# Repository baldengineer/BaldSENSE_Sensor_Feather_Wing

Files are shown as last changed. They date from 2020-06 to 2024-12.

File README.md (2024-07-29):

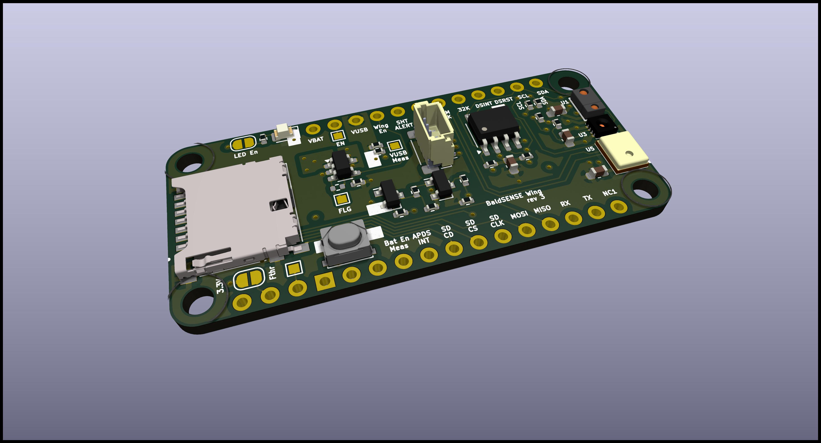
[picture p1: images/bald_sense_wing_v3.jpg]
render of BaldSENSE Sensor Feather Wing


## BaldSense Sensor Feather Wing
Project to fit a temperature, humidity, light, and sound sensor to an Adafruit Feather wing form factor.

Minimal environmental sensor board for characterizing a specific location. 

## Sensors Included:
- **Temp / Humidity**: 
    - SHT30-DIS-B2.5KS
- **Light**: 
    - APDS9960
- **Sound (Mic)**: 
    - MP34DT01TR-M
- **Real-Time Clock (RTC)**: 
    - DS3231S

## Status: Work In Progress
Originally created as a livestream project. Being updated for a long-term IoT project. 

V3 board fixes many issues with v1 and v2. Testing is underway with a [FeatherS3 board](https://unexpectedmaker.com/shop.html#!/FeatherS3/p/577111310/category=0) provided by [Unexpected Maker](https://unexpectedmaker.com). 

So far, each sensor is working as expected.

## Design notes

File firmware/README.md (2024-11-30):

Only [feathers3-cp](feathers3-cp/) is up-to-date.

It is basic logging code written in CircuitPython that works on a FeatherS3.

The `32u4` and `m0` code targeted rev2.

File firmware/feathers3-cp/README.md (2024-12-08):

# FeatherS3 Circuit Python

This code uses all of the intended BaldSENSE functions.

Couple of notes:
- Developed with a [FeatherS3](https://unexpectedmaker.com/shop.html#!/FeatherS3/p/577111310/category=0)
- Based on CircuitPython 9.x. 
- Publishes data to [Adafruit IO](https://io.adafruit.com)
    - It uses more feeds than the free version allows

## settings.toml.example
Remove the `.example` and place in the root directory of the `CIRCUITPY` mass storage device. 

### Required Settings:
- `WIFI_SSID` and `WIFI_PASSWORD` (your access point)
- `AIO_USERNAME` and `AIO_KEY` (Adafruit IO credentials)

### Optional, but recommended:
These settings have default values but you should set them.
- `BALDSENSE_ID` -> a unique identifier (defaults to `UNKNOWN`)
- `SLEEP_SECONDS` -> how long MCU goes to sleep between sampling (defaults to `600`)
- `WDT_SECONDS` -> watchdog timeout (defaults to `60`)
- `VUSB_THRESHOLD` -> voltage divider steps to detect when connected to power (defaults to `10000`)
- `UPDATE_TIME` -> force NTP update when connected to power. "No" or commented out skips this update.

### Not used (yet):
- `RUN_MODE` eventually to change behavior during devel or deploy
- `TIMEZONE` for setting timezone. current NTP method uses geo_ip
- `MQTT_BROKER` will use again in future to allow private broker

## Required Libraries
These are the required libraries. Dependencies are shown. The libraries listed with `.mpy` are single files and the others are directories in the [Adafruit CircuitPython (Library) Bundle](https://github.com/adafruit/Adafruit_CircuitPython_Bundle/releases). This code needs the `9.x` bundle.

### Sensors:
- adafruit_apds9960
- adafruit_ds3231.mpy
    - adafruit_register
- adafruit_sht31d.mpy

### AIO / MQTT:
- adafruit_io
- adafruit_minimqtt
    - adafruit_ticks.mpy
- adafruit_requests.mpy
    - adafruit_connection_manager

## mqtt_logger.py
Simple script to log MQTT messages to a file. Works well on Linux. 

## generate_time_string.py
Simple script to create a string with the system's current time to update the RTC. Copy/paste the string and press enter (line return). (You may need to re-enable the `while True` loop to get the timing right.)

Alternatively, when connected to USB, the code will check a NTP server.

## Sponsor
The PCB, components, and assembly for rev 3 have been provided by [MacroFab](https://macrofab.com).

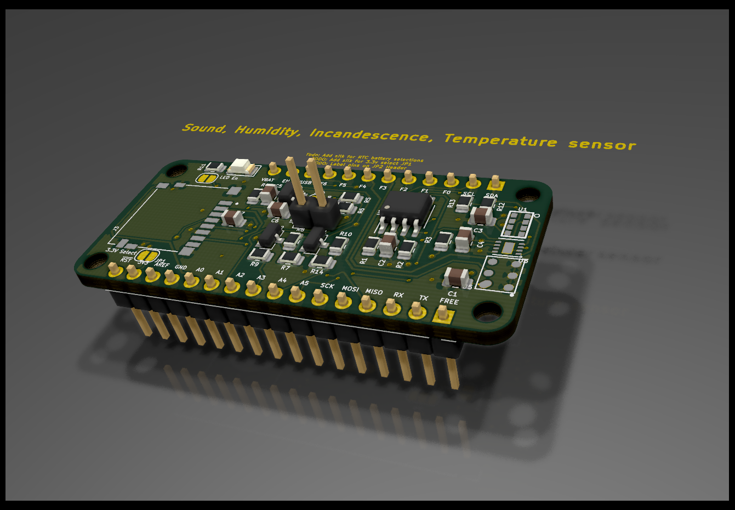
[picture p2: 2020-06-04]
images/Bald Sense Wing v1-second pass layout-ray.png

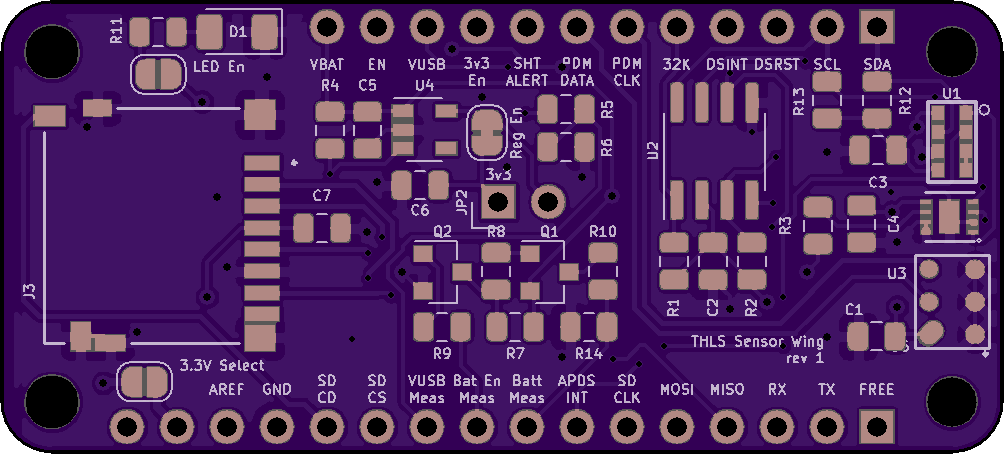
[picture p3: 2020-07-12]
images/pcb_render_oshpark_v1.png

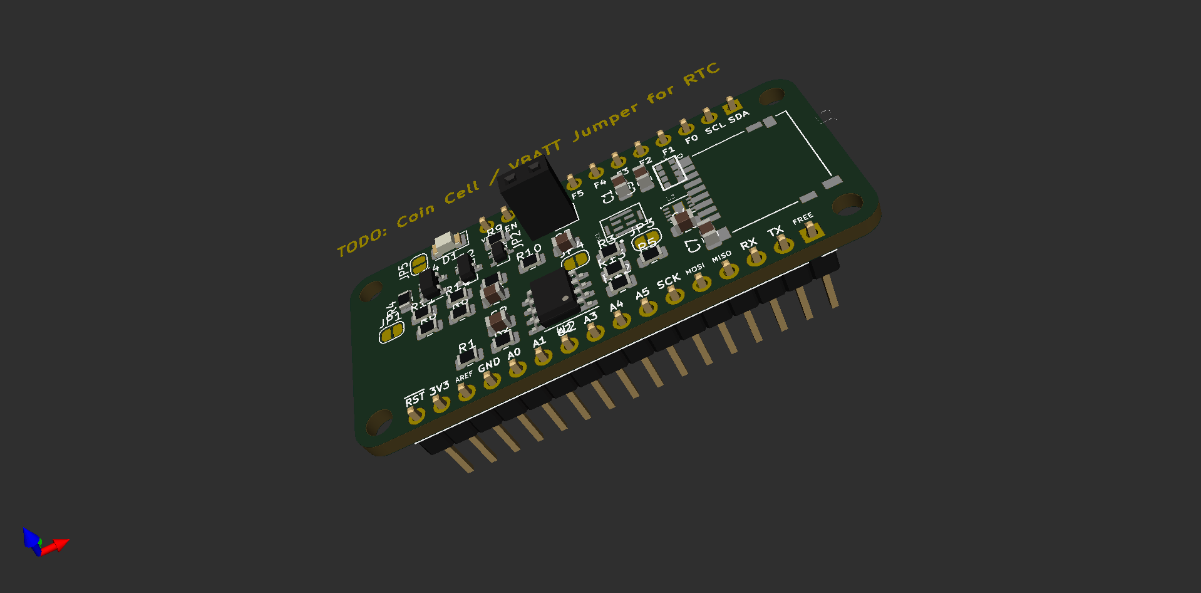
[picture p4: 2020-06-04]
images/Bald Sense Wing v1-first pass layout-flat.png

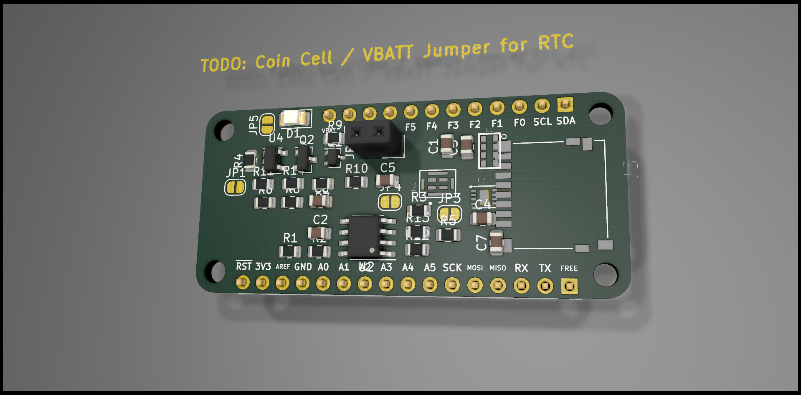
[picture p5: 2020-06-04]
images/Bald Sense Wing v1-first pass layout-ray.png

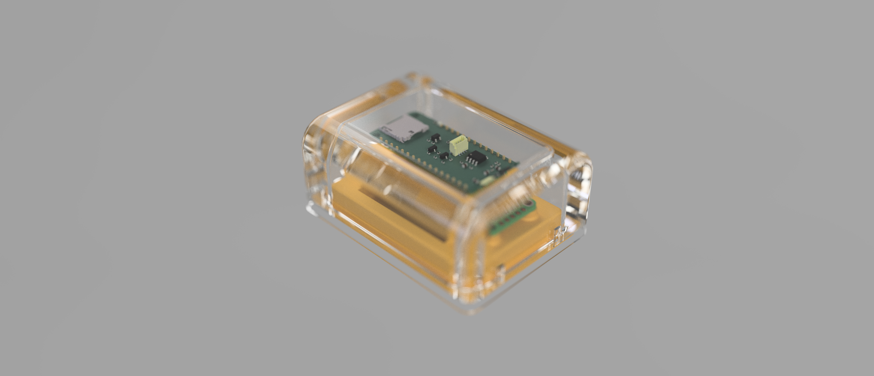
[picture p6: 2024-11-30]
enclosure/cover v7-polycarb with dof.png

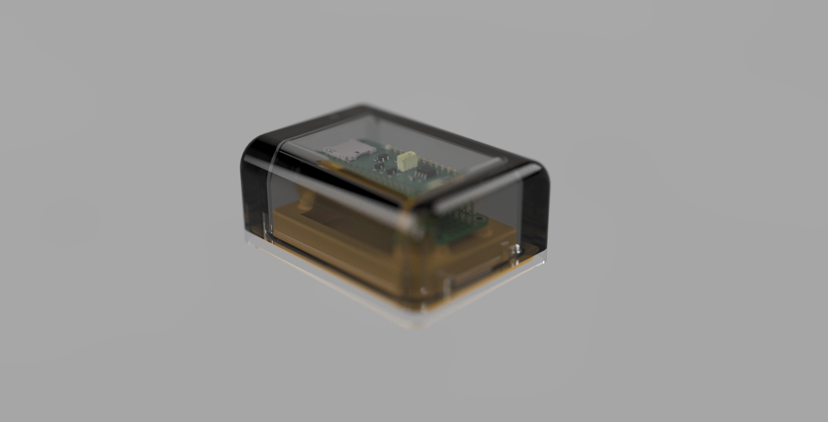
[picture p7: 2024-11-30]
enclosure/cover v7.png

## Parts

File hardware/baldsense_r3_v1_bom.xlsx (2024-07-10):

Designator | Value | Footprint | Populate | MPN | Manufacturer | MPN | Manufacturer
BT1 | 10mm | MPD_BK-870 | 0
C1 | 1uF | C_0603_1608Metric | 1 | LMK107B7105KAHT | Taiyo Yuden | MF-CAP-0805-1uF | MacroFab
C2 | 1uF | C_0603_1608Metric | 1 | LMK107B7105KAHT | Taiyo Yuden | MF-CAP-0805-1uF | MacroFab
C3 | 1uF | C_0603_1608Metric | 1 | LMK107B7105KAHT | Taiyo Yuden | MF-CAP-0805-1uF | MacroFab
C4 | 1uF | C_0603_1608Metric | 1 | LMK107B7105KAHT | Taiyo Yuden | MF-CAP-0805-1uF | MacroFab
C7 | 1uF | C_0603_1608Metric | 0 | LMK107B7105KAHT | Taiyo Yuden | MF-CAP-0805-1uF | MacroFab
D1 | PWR_LED | LED_0805_2012Metric | 1 | MF-LED-0805-GREEN | MacroFab
J1 | feather long | PinHeader_1x16_P2.54mm_Vertical | 0
J2 | feather short | PinHeader_1x12_P2.54mm_Vertical | 0
J3 | 1140084168 | AMPHENOL_1140084168 | 1 | 1140084168 | Amphenol
J4 | STEMMA-QT | JST_SH_BM04B-SRSS-TB_1x04-1MP_P1.00mm_Vertical | 0
JP1 | 3.3V | SolderJumper-2_P1.3mm_Open_RoundedPad1.0x1.5mm | 0
JP2 | RTC Batt Select | SolderJumper-3_P1.3mm_Bridged12_RoundedPad1.0x1.5mm | 0
JP3 | SHT30-Alert | SolderJumper-2_P1.3mm_Open_RoundedPad1.0x1.5mm | 0
JP5 | LED En | SolderJumper-2_P1.3mm_Open_RoundedPad1.0x1.5mm | 0
JP6 | RTC Batt Select | SolderJumper-3_P1.3mm_Bridged12_RoundedPad1.0x1.5mm | 0
Q1 | Q_PNP_BEC | SOT-23 | 1 | MMBT3906LT3G | onsemi | MF-DSC-SOT233-MMBT3906 | MacroFab
Q2 | Q_NPN_BEC | SOT-23 | 1 | MMBT3904LT3G | onsemi | MF-DSC-SOT233-MMBT3904 | MacroFab
R1 | 10K | R_0402_1005Metric | 1 | MF-RES-0402-10K | MacroFab
R10 | 10K | R_0402_1005Metric | 1 | MF-RES-0402-10K | MacroFab
R11 | 1K | R_0402_1005Metric | 1 | MF-RES-0402-1K | MacroFab
R12 | 10K | R_0402_1005Metric | 1 | MF-RES-0402-10K | MacroFab
R13 | 10K | R_0402_1005Metric | 1 | MF-RES-0402-10K | MacroFab
R14 | 10K | R_0402_1005Metric | 1 | MF-RES-0402-10K | MacroFab
R15 | 10K | R_0402_1005Metric | 0 | MF-RES-0402-10K | MacroFab
R16 | 10K | R_0402_1005Metric | 1 | MF-RES-0402-10K | MacroFab
R2 | 10K | R_0402_1005Metric | 1 | MF-RES-0402-10K | MacroFab
R3 | 10K | R_0402_1005Metric | 1 | MF-RES-0402-10K | MacroFab
R4 | 10K | R_0402_1005Metric | 1 | MF-RES-0402-10K | MacroFab
R5 | 10K | R_0402_1005Metric | 1 | MF-RES-0402-10K | MacroFab
R6 | 10K | R_0402_1005Metric | 1 | MF-RES-0402-10K | MacroFab
R7 | 10K | R_0402_1005Metric | 1 | MF-RES-0402-10K | MacroFab
R8 | 1K | R_0402_1005Metric | 1 | MF-RES-0402-1K | MacroFab
R9 | 1K | R_0402_1005Metric | 1 | MF-RES-0402-1K | MacroFab
SW1 | PTS810 | SW_SPST_PTS810_with_3D | 1 | PTS810SJK250SMTRLFS | C&K Components
TP1 | Test Point | TestPoint_Pad_1.0x1.0mm | 0
TP2 | Test Point | TestPoint_Pad_1.0x1.0mm | 0
TP3 | Test Point | TestPoint_Pad_1.0x1.0mm | 0
TP4 | Test Point | TestPoint_Pad_1.0x1.0mm | 0
TP5 | Test Point | TestPoint_Pad_1.0x1.0mm | 0
TP6 | Test Point | TestPoint_Pad_1.0x1.0mm | 0
TP7 | FLG | TestPoint_Pad_1.0x1.0mm | 0
TP8 | Test Point | TestPoint_Pad_1.0x1.0mm | 0
U1 | APDS-9960 | APDS-9960 | 1 | APDS-9960 | Broadcom
U2 | DS3231MZ | SOIC-8_3.9x4.9mm_P1.27mm | 1 | DS3231MZ | Dallas Semiconductor | DS3231MZ+ | Analog Devices
U3 | SHT30-DIS | DFN250X250X100-9N | 1 | SHT30-DIS | Sensirion | SHT30-DIS-P2.5KS | Sensirion
U4 | AP2151AW-7 | SOT-23-5 | 1 | AP2151AW-7 | Diodes Inc.
U5 | CMM-4737DT-26186-TR | XDCR_CMM-4737DT-26186-TR | 1 | CMM-4737DT-26186-TR | CUI Devices

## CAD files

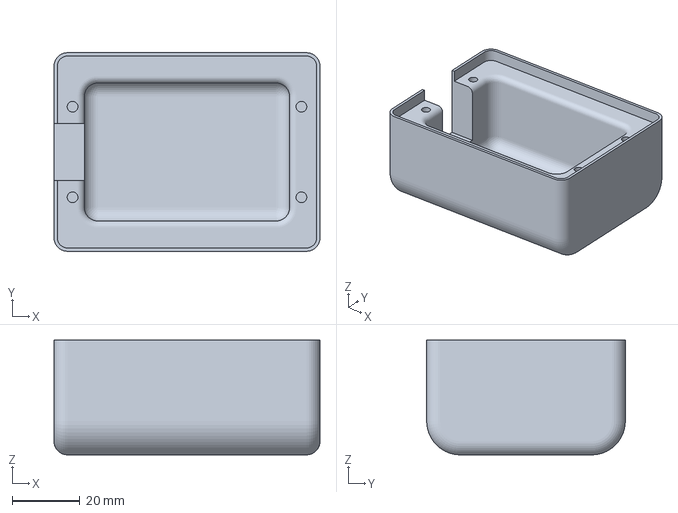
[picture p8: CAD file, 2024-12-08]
enclosure/Cover with USB Cutout.3mf
78.8 x 58.9 x 34.0 mm

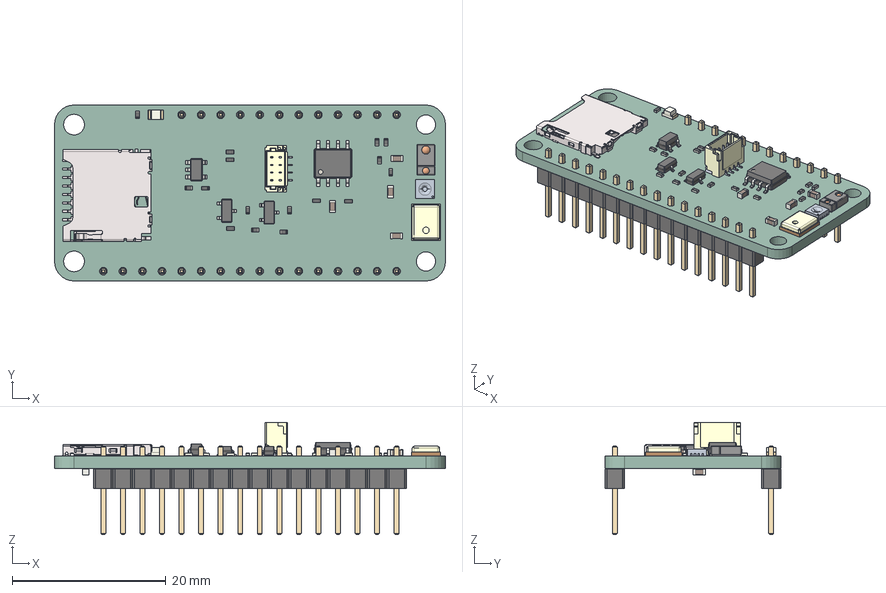
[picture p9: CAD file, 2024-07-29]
hardware/Bald Sense Wing v3.step
50.8 x 22.9 x 14.6 mm
C_0603_1608Metric x 5
LED_0805_2012Metric
R_0402_1005Metric x 16
ECA50C62-ABC2-4892-9E4C-4FA133A4C33F
SOIC_8_39x49mm_P127mm
CUI_DEVICES_CMM-4737DT-26186-TR
SOT_23 x 2
User Library-SHT3x
SOT_23_5
BM04B-SRSS-TBT(LF)(SN)
PinHeader_1x16_P254mm_Vertical
PinHeader_1x12_P254mm_Vertical
Bald Sense Wing v3_PCB

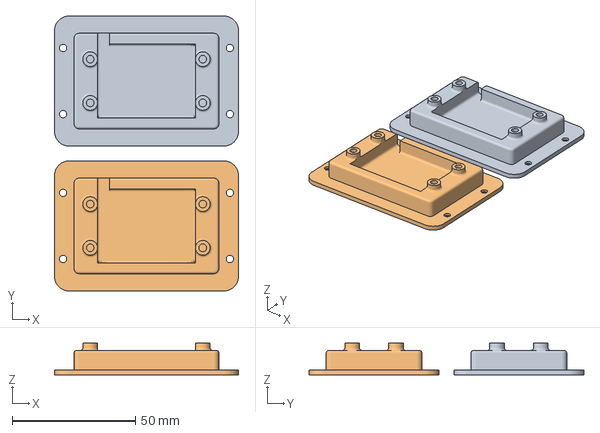
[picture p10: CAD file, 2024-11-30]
enclosure/Baseplate.3mf
74.8 x 111.7 x 13.0 mm
Baseplate.stl x 2

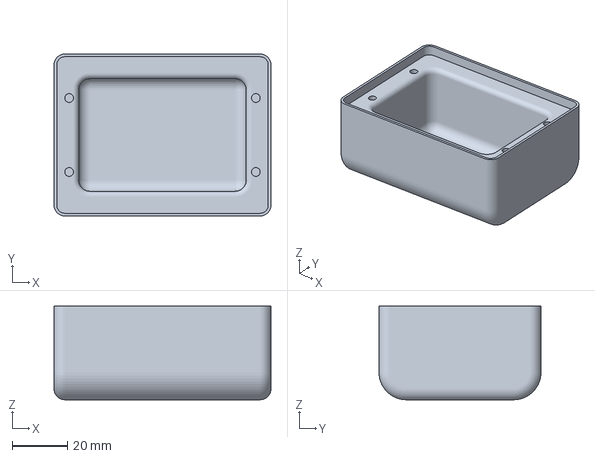
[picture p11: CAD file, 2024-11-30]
enclosure/Cover.3mf
78.8 x 58.9 x 34.0 mm

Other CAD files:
enclosure/Baseplate.stl
enclosure/Cover with USB Cutout.stl
enclosure/Cover.stl

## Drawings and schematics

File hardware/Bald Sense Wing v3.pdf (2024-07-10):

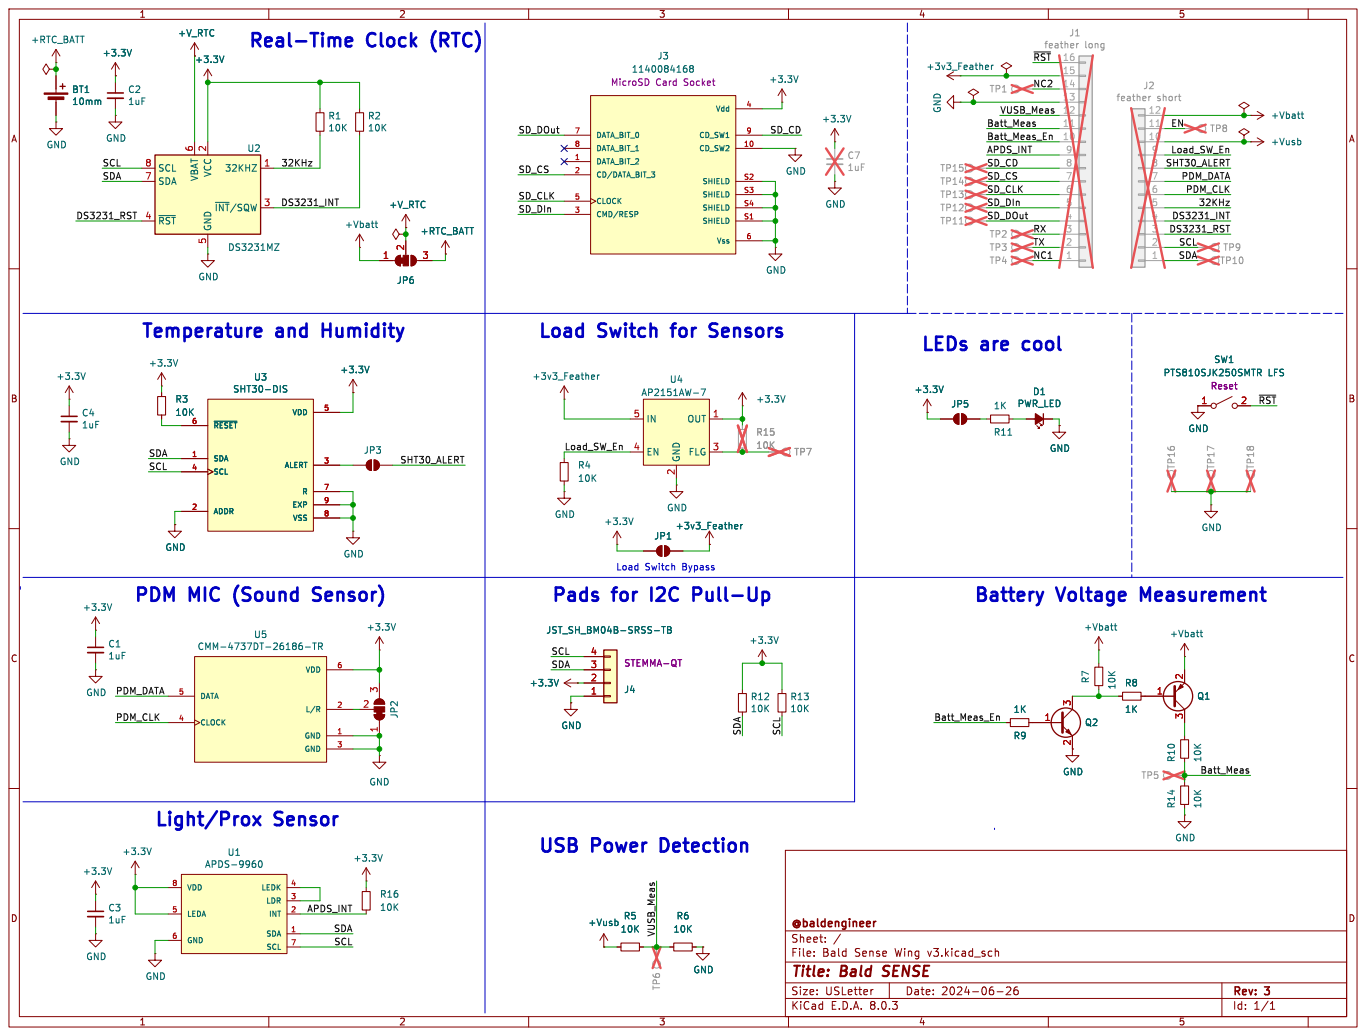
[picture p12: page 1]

6 SDA 7 SCL 8 U2 DS3231MZ GND GND GND

Load Switch for Sensors

Load Switch Bypass
Pads for I2C Pull-Up

Id: 1/1 Title: Bald SENSE

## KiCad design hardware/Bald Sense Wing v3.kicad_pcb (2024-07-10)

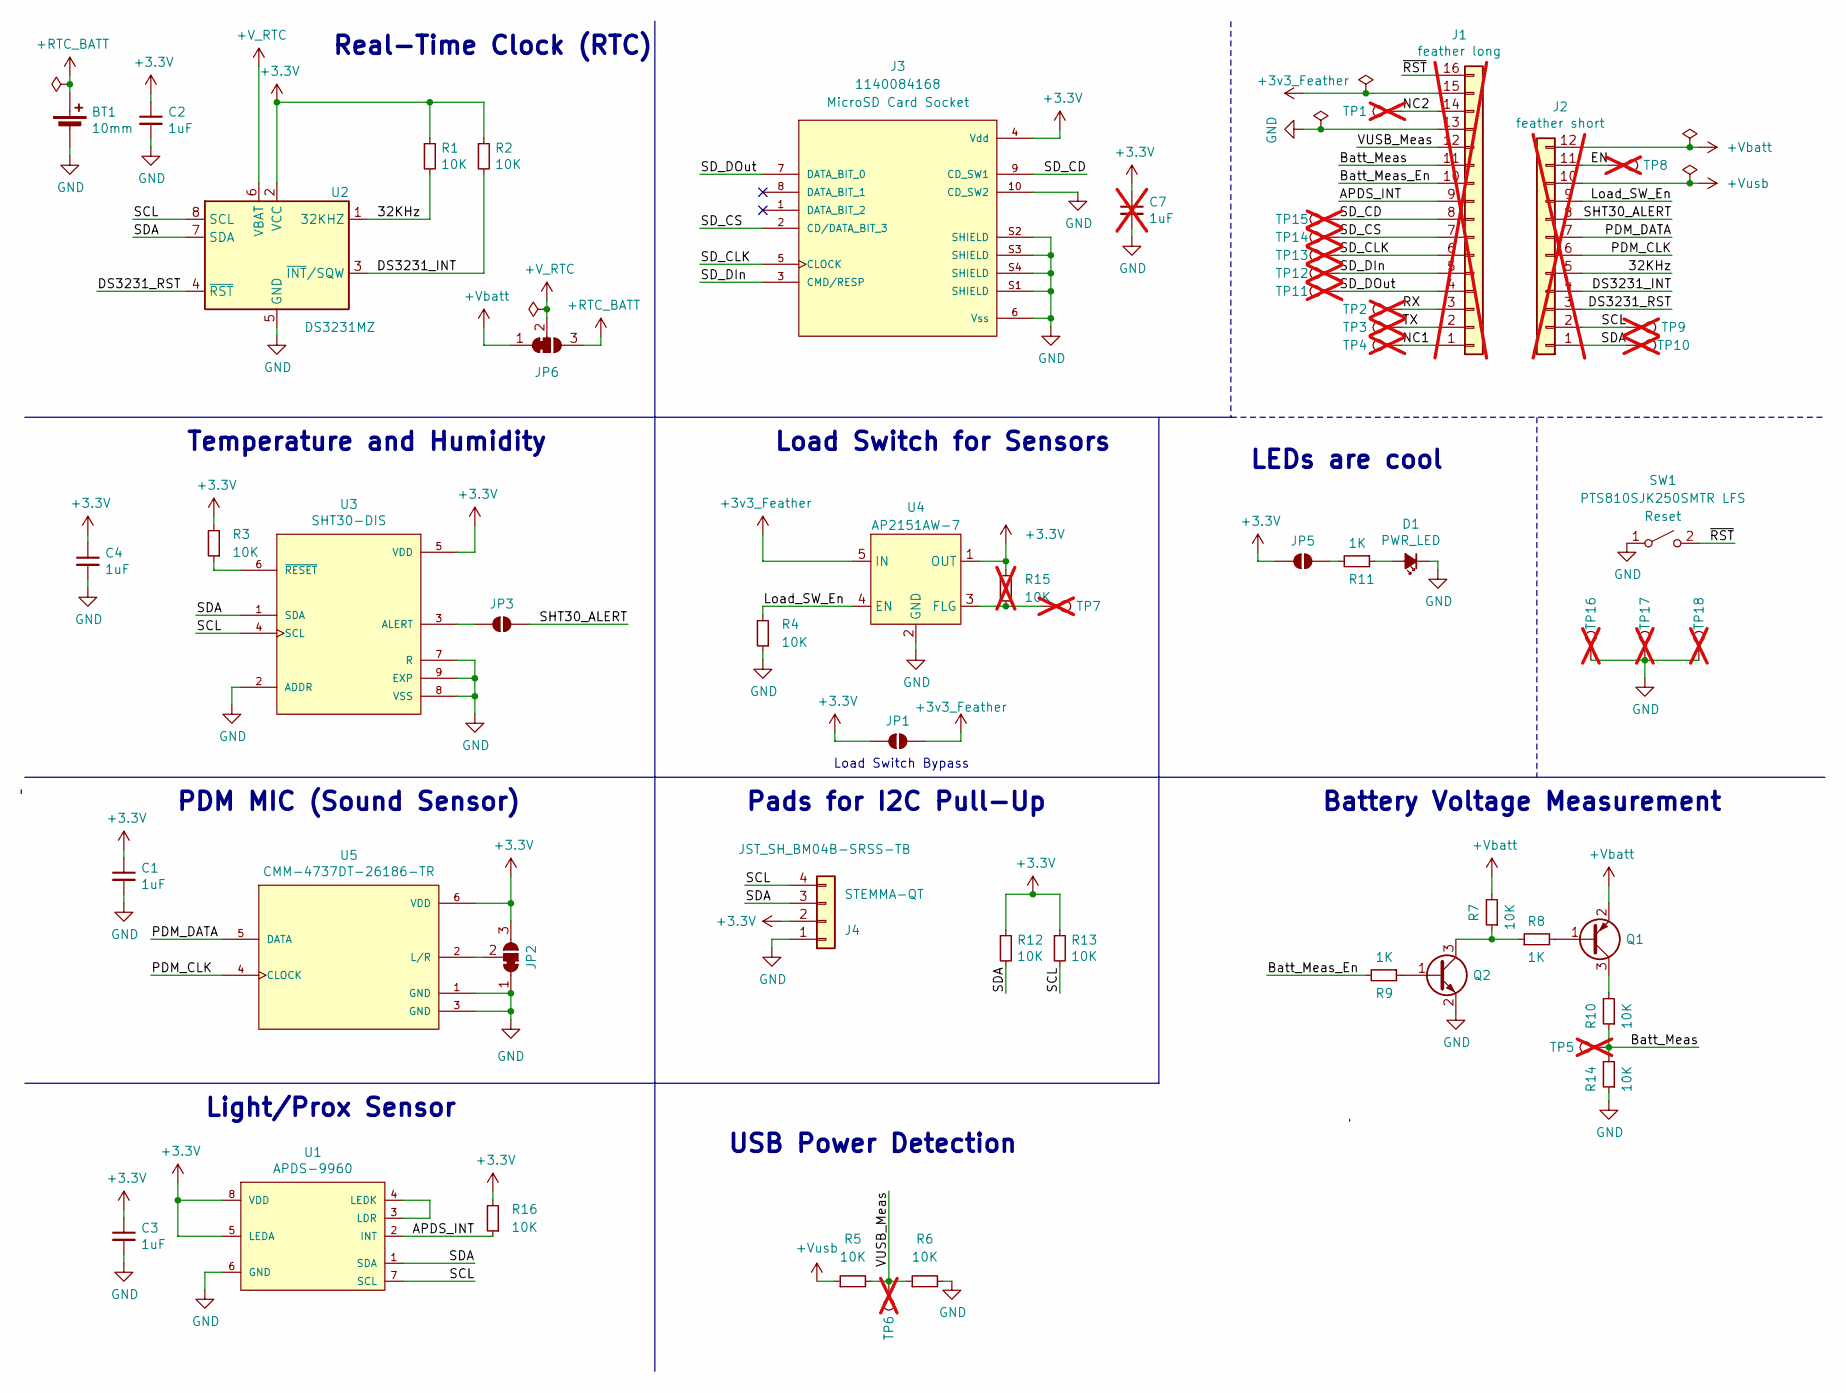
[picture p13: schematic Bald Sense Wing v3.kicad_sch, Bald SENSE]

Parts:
BT1: 10mm; MPD_BK-870
C1, C2, C3, C4: 1uF; C_0603_1608Metric
C7: 1uF; C_0603_1608Metric; not fitted
D1: PWR_LED; LED_0805_2012Metric
J1: feather long; PinHeader_1x16_P2.54mm_Vertical; not fitted
J2: feather short; PinHeader_1x12_P2.54mm_Vertical; not fitted
J3: 1140084168; AMPHENOL_1140084168
J4: JST_SH_BM04B-SRSS-TB; JST_SH_BM04B-SRSS-TB_1x04-1MP_P1.00mm_Vertical
JP1: 3.3V Select; SolderJumper-2_P1.3mm_Open_RoundedPad1.0x1.5mm
JP2, JP6: RTC Batt Select; SolderJumper-3_P1.3mm_Bridged12_RoundedPad1.0x1.5mm
JP3: SHT30-Alert; SolderJumper-2_P1.3mm_Open_RoundedPad1.0x1.5mm
JP5: LED En; SolderJumper-2_P1.3mm_Open_RoundedPad1.0x1.5mm
Q1: Q_PNP_BEC; SOT-23; MPN MMBT3906LT3G
Q2: Q_NPN_BEC; SOT-23; MPN MMBT3904LT3G
R1, R2, R3, R4, R5, R6, R7, R10, R12, R13, R14, R16: 10K; R_0402_1005Metric
R8, R9, R11: 1K; R_0402_1005Metric
R15: 10K; R_0402_1005Metric; not fitted
SW1: PTS810SJK250SMTR LFS; SW_SPST_PTS810
TP1, TP2, TP3, TP4, TP5, TP6, TP8, TP9, TP10, TP11, TP12, TP13, TP14, TP15, TP16, TP17, TP18: Test Point; TestPoint_Pad_1.0x1.0mm; not fitted
TP7: FLG; TestPoint_Pad_1.0x1.0mm; not fitted
U1: APDS-9960
U2: DS3231MZ; SOIC-8_3.9x4.9mm_P1.27mm
U3: SHT30-DIS; DFN250X250X100-9N
U4: AP2151AW-7; SOT-23-5
U5: CMM-4737DT-26186-TR; XDCR_CMM-4737DT-26186-TR

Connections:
+3.3V: C1.1, C2.1, C3.1, C4.1, C7.1, J3.4 (Vdd), J4.2, JP1.1 (A), JP2.3 (B), JP5.1 (A), R1.1, R2.1, R3.2, R12.1, R13.1, R15.2, R16.2, U1.5 (LEDA), U1.8 (VDD), U2.2 (VCC), U3.5 (VDD), U4.1 (OUT), U5.6 (VDD)
+3v3_Feather: J1.15, JP1.2 (B), U4.5 (IN)
+RTC_BATT: BT1.1 (+), JP6.3 (B)
+V_RTC: JP6.2 (C), U2.6 (VBAT)
+Vbatt: J2.12, JP6.1 (A), Q1.2 (E), R7.2
+Vusb: J2.10, R5.1
/32KHz: J2.5, R1.2, U2.1 (32KHZ)
/APDS_INT: J1.9, R16.1, U1.2 (INT)
/Batt_Meas: J1.11, R10.1, R14.2, TP5.1
/Batt_Meas_En: J1.10, R9.2
/DS3231_INT: J2.4, R2.2, U2.3 (~INT/SQW)
/DS3231_RST: J2.3, U2.4 (~RST)
/EN: J2.11, TP8.1
/Load_SW_En: J2.9, R4.2, U4.4 (EN)
/NC1: J1.1, TP4.1
/NC2: J1.14, TP1.1
/PDM_CLK: J2.6, U5.4 (CLOCK)
/PDM_DATA: J2.7, U5.5 (DATA)
/RX: J1.3, TP2.1
/SCL: J2.2, J4.4, R13.2, TP9.1, U1.7 (SCL), U2.8 (SCL), U3.4 (SCL)
/SDA: J2.1, J4.3, R12.2, TP10.1, U1.1 (SDA), U2.7 (SDA), U3.1 (SDA)
/SD_CD: J1.8, J3.9 (CD_SW1), TP15.1
/SD_CLK: J1.6, J3.5 (CLOCK), TP13.1
/SD_CS: J1.7, J3.2 (CD/DATA_BIT_3), TP14.1
/SD_DIn: J1.5, J3.3 (CMD/RESP), TP12.1
/SD_DOut: J1.4, J3.7 (DATA_BIT_0), TP11.1
/SHT30_ALERT: J2.8, JP3.2 (B)
/TX: J1.2, TP3.1
/VUSB_Meas: J1.12, R5.2, R6.1, TP6.1
/~RST: J1.16, SW1.2 (B)
GND: BT1.2 (-), C1.2, C2.2, C3.2, C4.2, C7.2, D1.1 (K), J1.13, J3.6 (Vss), J3.10 (CD_SW2), J3.S1 (SHIELD), J3.S2 (SHIELD), J3.S3 (SHIELD), J3.S4 (SHIELD), J4.1, JP2.1 (A), Q2.2 (E), R4.1, R6.2, R14.1, SW1.1 (A), TP16.1, TP17.1, TP18.1, U1.6 (GND), U2.5 (GND), U3.2 (ADDR), U3.7 (R), U3.8 (VSS), U3.9 (EXP), U4.2 (GND), U5.1 (GND), U5.3 (GND)
unnamed: D1.2 (A), R11.1
unnamed: JP2.2 (C), U5.2 (L/R)
unnamed: JP3.1 (A), U3.3 (ALERT)
unnamed: JP5.2 (B), R11.2
unnamed: Q1.1 (B), R8.2
unnamed: Q1.3 (C), R10.2
unnamed: Q2.1 (B), R9.1
unnamed: Q2.3 (C), R7.1, R8.1
unnamed: U1.3 (LDR), U1.4 (LEDK)
unnamed: R3.1, U3.6 (~RESET)
unnamed: R15.1, TP7.1, U4.3 (FLG)

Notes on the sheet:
Light/Prox Sensor
Temperature and Humidity
Pads for I2C Pull-Up
PDM MIC (Sound Sensor)
Real-Time Clock (RTC)
Load Switch for Sensors
Load Switch Bypass
LEDs are cool
Battery Voltage Measurement
USB Power Detection

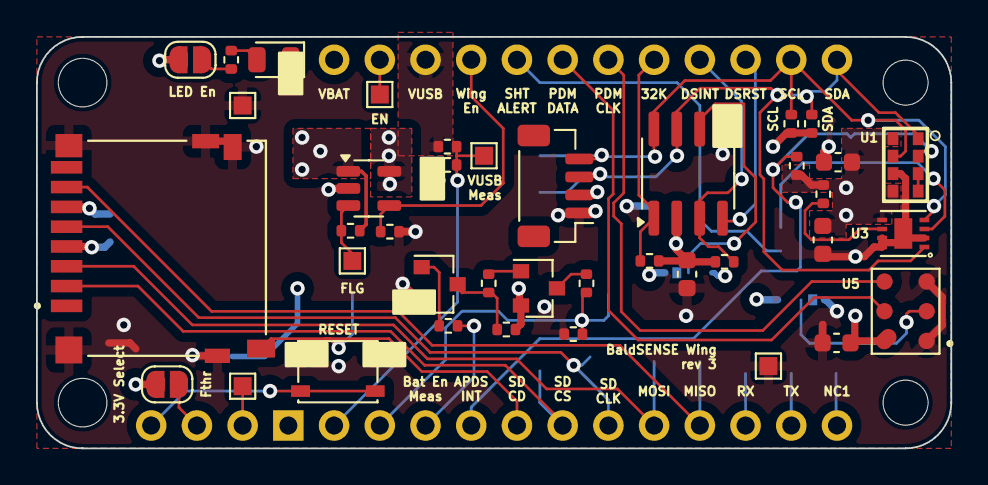
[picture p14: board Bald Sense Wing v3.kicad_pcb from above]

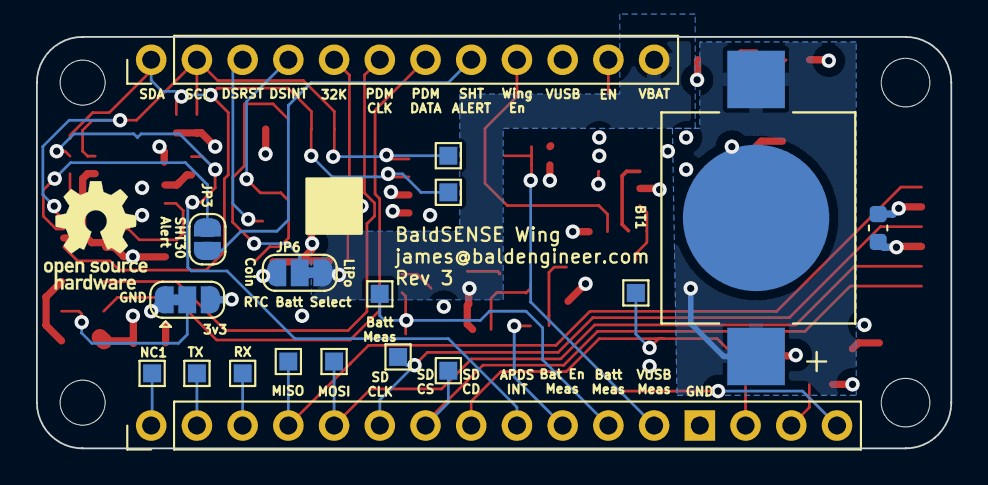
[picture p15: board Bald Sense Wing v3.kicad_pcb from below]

Board: 4 copper layers, 50.8 x 22.9 mm, 58 parts (19 on the bottom side), 42 nets.

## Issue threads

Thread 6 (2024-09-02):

Alternative firmware

bablokb, 2024-09-02:
A very nice project. I have created something similar (see https://github.com/bablokb/pcb-pico-datalogger). Difference are mainly other sensors, and a dedicated base-pcb (instead of the Feather-format). This allows clean panel mounting of the sensors without exposing other electronics.

My datalogger firmware is extremely flexible and configurable. To run on your device, it probably only needs a pin-mapping file, support for the RTC and some small wrappers for your specific sensors.

Closed 2024-09-02.

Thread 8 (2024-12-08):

Add button for Pseudo-boot mode

baldengineer, 2024-12-08:
Press button, reset, spin in a loop to do whatever.

Just to prevent connecting to Wi-Fi and Broker.

baldengineer, 2024-12-08:
or make use of `RUN_MODE` ...

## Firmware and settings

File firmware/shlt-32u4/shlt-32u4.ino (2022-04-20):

// wait 60 seconds (testing 10 seconds)
// get the current date/time
// get the temperature and humidity
// put them to sd card

// Date and time functions using a DS3231 RTC connected via I2C and Wire lib
#include <Wire.h>
#include "RTClib.h"

// sht30 (temp/humdity) stuff
#include <Wire.h>
#include "ClosedCube_SHT31D.h"

// stuff for SD Card
#include <SPI.h>
#include <SD.h>

ClosedCube_SHT31D sht3xd;


// Global Stuff
char time_stamp_string[21];
char temp_humd_string[16];
File myFile;

// RTC Stuff
RTC_DS3231 rtc;
//char daysOfTheWeek[7][12] = {"Sunday", "Monday", "Tuesday", "Wednesday", "Thursday", "Friday", "Saturday"};

// State Machine stuff
unsigned long previous_print_millis = 0;
unsigned long print_interval = 2500;

byte init_rtc() {
  if (!rtc.begin()) {
    Serial.println("Couldn't find RTC");
    return 0; // failed to get rtc
  }

  if (rtc.lostPower()) {
    Serial.println("RTC lost power, lets set the time!");
    // following line sets the RTC to the date & time this sketch was compiled
    rtc.adjust(DateTime(F(__DATE__), F(__TIME__)));
    // This line sets the RTC with an explicit date & time, for example to set
    // January 21, 2014 at 3am you would call:
    // rtc.adjust(DateTime(2014, 1, 21, 3, 0, 0));
    return 2; // successful return, but know the time changed
  }

  return 1; // successful init
}

byte init_sht30() {
    Serial.println("ClosedCube SHT3X-D Single Shot Mode Example");
    Serial.println("supports SHT30-D, SHT31-D and SHT35-D");

    sht3xd.begin(0x44); // I2C address: 0x44 or 0x45

    Serial.print("Serial #");
    Serial.println(sht3xd.readSerialNumber());

    return 1;
}

byte init_sdcard() {
    Serial.print("Initializing SD card...");

    if (!SD.begin(A1)) {
        Serial.println("initialization failed!");
        return 0; // fail!
    }
    Serial.println("initialization done.");
    myFile = SD.open("test.txt", FILE_WRITE);

    // if file opened okay:
    if (myFile) {
        Serial.print("Writing Header to SD...");
        myFile.println("DATE, TIME, Temperature, Humidity");
        myFile.close();
        Serial.println("done!");
    } else {
        return 0; // couldn't write
    }
    return 1;
}

void setup () {
    Wire.begin();
    Serial.begin(9600);
    //while(!Serial);

    delay(3000); // wait for console opening

    // connect to sd card
    init_sdcard();

    // connect to SHT30 (temp and sensor)
    init_sht30();

    // connect to DS3231 (real-time clock)
    init_rtc();

}

void loop () {

    unsigned current_millis = millis();
    if (current_millis - previous_print_millis >= print_interval) {
        get_time_stamp();
        Serial.print(time_stamp_string);
        Serial.print(",");

        get_sht30_data();
        Serial.print(temp_humd_string);

        myFile = SD.open("test.txt", FILE_WRITE);
         myFile.print(time_stamp_string);
         myFile.print(",");
         myFile.println(temp_humd_string);
        myFile.close();

        //sht30 stuff.
      //  print_sht30_result("ClockStrech Mode", sht3xd.readTempAndHumidity(SHT3XD_REPEATABILITY_LOW, SHT3XD_MODE_CLOCK_STRETCH, 50));
      //  delay(250);
     //   print_sht30_result("Pooling Mode", sht3xd.readTempAndHumidity(SHT3XD_REPEATABILITY_HIGH, SHT3XD_MODE_POLLING, 50));

        Serial.println();

        // reset the clock
        previous_print_millis = current_millis;
    }

//    delay(3000);
}

void get_time_stamp() {
    DateTime now = rtc.now();

    // 2020-07-08,21:20:57

    sprintf(time_stamp_string, "%d-%02d-%02d,%02d:%02d:%02d",
        now.year(),
        now.month(),
        now.day(),
        now.hour(),
        now.minute(),
        now.second()
        );
/*    
    Serial.print(now.year(), DEC);
    Serial.print('-');
    Serial.print(now.month(), DEC);
    Serial.print('-');
    Serial.print(now.day(), DEC);

    Serial.print(" (");
    Serial.print(daysOfTheWeek[now.dayOfTheWeek()]);
    Serial.print(") ");
    Serial.print(",");
    Serial.print(now.hour(), DEC);
    Serial.print(':');
    Serial.print(now.minute(), DEC);
    Serial.print(':');
    Serial.print(now.second(), DEC);
    Serial.println();
    */


/*    
    Serial.print(" since midnight 1/1/1970 = ");
    Serial.print(now.unixtime());
    Serial.print("s = ");
    Serial.print(now.unixtime() / 86400L);
    Serial.println("d");

   
    // calculate a date which is 7 days and 30 seconds into the future
    DateTime future (now + TimeSpan(7,12,30,6));
    
    Serial.print(" now + 7d + 30s: ");
    Serial.print(future.year(), DEC);
    Serial.print('/');
    Serial.print(future.month(), DEC);
    Serial.print('/');
    Serial.print(future.day(), DEC);
    Serial.print(' ');
    Serial.print(future.hour(), DEC);
    Serial.print(':');
    Serial.print(future.minute(), DEC);
    Serial.print(':');
    Serial.print(future.second(), DEC);
    Serial.println();*/
    
  //  Serial.println();
}


/* This is example for SHT3X-DIS Digital Humidity & Temperature Sensors Arduino Library
ClosedCube SHT31-D [Digital I2C] Humidity and Temperature Sensor Breakout
MIT License
*/

// print_sht30_result("Pooling Mode", sht3xd.readTempAndHumidity(SHT3XD_REPEATABILITY_HIGH, SHT3XD_MODE_POLLING, 50));

void get_sht30_data() {
    SHT31D result = sht3xd.readTempAndHumidity(SHT3XD_REPEATABILITY_HIGH, SHT3XD_MODE_POLLING, 50);
    if (result.error == SHT3XD_NO_ERROR) {
        // 100.0C,100.0%


       // Serial.print(text);
      //  Serial.print(",T=");
//}

/*dtostrf(floatvar, StringLengthIncDecimalPoint, numVarsAfterDecimal, charbuf);

where
floatvar    float variable
StringLengthIncDecimalPoint     This is the length of the string that will be created
numVarsAfterDecimal     The number of digits after the deimal point to print
charbuf     the array to store the results*/

        char temp_str[8];
        dtostrf(result.t, 5, 1, temp_str);

        char humd_str[8];
        dtostrf(result.rh, 5, 1, humd_str);
       // sprintf(temp_humd_string, "%fC,%f%", result.t, result,rh);
        sprintf(temp_humd_string, "%sC,%s%%", temp_str, humd_str);

   /*     Serial.print(",");
        Serial.print(result.t);
        //Serial.print("C, RH=");
        Serial.print("C,");
        Serial.print(result.rh);
        Serial.println("%");*/
    } else {
        //Serial.print(text);
      /*  Serial.print(":[ERROR] Code #");
        Serial.println(result.error);*/
        sprintf(temp_humd_string, "ERR:%d", result.error);
    }
}

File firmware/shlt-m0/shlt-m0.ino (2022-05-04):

// wait 60 seconds (testing 10 seconds)
// get the current date/time
// get the temperature and humidity
// put them to sd card

// Date and time functions using a DS3231 RTC connected via I2C and Wire lib
#include <Wire.h>
#include "RTClib.h"

// sht30 (temp/humdity) stuff
#include <Wire.h>
#include "ClosedCube_SHT31D.h"
#include <Adafruit_SleepyDog.h>

// stuff for SD Card
#include <SPI.h>
#include <SD.h>

// APDS-9660 Proximity Sensor
#include <Arduino_APDS9960.h>

ClosedCube_SHT31D sht3xd;

const uint8_t LED_PIN=13;

// Global Stuff
char time_stamp_string[21];
char temp_humd_string[21];
char file_name[30];
char color_sensor_string[21];
File myFile;

// RTC Stuff
RTC_DS3231 rtc;
//char daysOfTheWeek[7][12] = {"Sunday", "Monday", "Tuesday", "Wednesday", "Thursday", "Friday", "Saturday"};

// State Machine stuff
unsigned long previous_print_millis = 0;
unsigned long print_interval = 2500;
int r, g, b, a;

byte init_adps() {
    Serial.print(("ADPS Init..."));
    if (!APDS.begin()) {
      Serial.println("Failed.");
      while (true); // Stop forever
      return 0;
    }
  Serial.println(F("DONE!"));
  return 1;
}

byte init_rtc() {
  if (!rtc.begin()) {
    Serial.println(F("Couldn't find RTC"));
    return 0; // failed to get rtc
  }

  if (rtc.lostPower()) {
    Serial.println(F("RTC lost power, lets set the time!"));
    // following line sets the RTC to the date & time this sketch was compiled
    rtc.adjust(DateTime(F(__DATE__), F(__TIME__)));
    // This line sets the RTC with an explicit date & time, for example to set
    // January 21, 2014 at 3am you would call:
    // rtc.adjust(DateTime(2014, 1, 21, 3, 0, 0));
    return 2; // successful return, but know the time changed
  }

  return 1; // successful init
}

byte init_sht30() {
    sht3xd.begin(0x44); // I2C address: 0x44 or 0x45

    Serial.print(F("sht30 serial #: "));
    Serial.println(sht3xd.readSerialNumber());

    return 1;
}

byte init_sdcard() {
    Serial.print(F("Initializing SD card..."));
    if (!SD.begin(A1)) {
        Serial.println(F("failed!"));
        return 0; // fail!
    }

    DateTime now = rtc.now();

    sprintf(file_name, "test-%02d.txt", now.minute());

    Serial.println(F("done."));
    Serial.print(F("Filename: "));
    Serial.println(file_name);
    myFile = SD.open(file_name, FILE_WRITE);

    // if file opened okay:
    if (myFile) {
        Serial.print(F("Writing Header to SD..."));
        myFile.println("DATE, TIME, Temperature, Humidity, R, G, B, Ambient");
        myFile.close();
        Serial.println(F("done!"));
    } else {
        return 0; // couldn't write
    }
    return 1;
}

char *dtostrf (double val, signed char width, unsigned char prec, char *sout) {
  char fmt[20];
  sprintf(fmt, "%%%d.%df", width, prec);
  sprintf(sout, fmt, val);
  return sout;
}

void setup () {
    Wire.begin();
    Serial.begin(9600);

    pinMode(0, OUTPUT);
    digitalWrite(0, LOW);
    pinMode(1, OUTPUT);
    digitalWrite(1, LOW);
    pinMode(LED_PIN, OUTPUT);

    for (int x=0; x<4; x++) {
      digitalWrite(LED_PIN, HIGH);
      delay(250);
      digitalWrite(LED_PIN, LOW);
      delay(250);
    }
   // while(!Serial);

    init_rtc();    // DS3231 
    init_sdcard(); // sd card
    init_sht30();  // temp and humidity
    init_adps();   // color and light
}

void loop () {
      const int meas_wait = 100;
      delay(meas_wait);
      digitalWrite(LED_PIN, LOW);
      int sleepMS = Watchdog.sleep(5000); 
      USBDevice.attach();  // re-attach for M0's USB CDC
      //delay(5000);
      digitalWrite(LED_PIN, HIGH);
  
      delay(meas_wait); 
      digitalWrite(0, HIGH);
       get_time_stamp();
       Serial.print(time_stamp_string);
       Serial.print(F(","));
      digitalWrite(0, LOW);
  
      delay(meas_wait);
      digitalWrite(0, HIGH);
       get_sht30_data();
       Serial.print(temp_humd_string);
      digitalWrite(0, LOW);

    delay(meas_wait);  
    digitalWrite(0, HIGH);
     if (APDS.colorAvailable()) {
       // rrr,ggg,bbb,aaa
       APDS.readColor(r, g, b, a);
       sprintf(color_sensor_string, "%03d, %03d, %03d, %03d", r,g,b,a);
     } else {
       r = 0;
       g = 0;
       b = 0;
       a = 0;
     }
     Serial.print(color_sensor_string);
    digitalWrite(0, LOW);

    delay(meas_wait);
    
    digitalWrite(1, HIGH);
     myFile = SD.open(file_name, FILE_WRITE);
       myFile.print(time_stamp_string);
       myFile.print(",");
       myFile.print(temp_humd_string);
       myFile.print(",");
       myFile.println(color_sensor_string);
     myFile.close();
    digitalWrite(1, LOW);

    Serial.println();
}

void get_time_stamp() {
    DateTime now = rtc.now();

    // 2020-07-08,21:20:57
    sprintf(time_stamp_string, "%d-%02d-%02d,%02d:%02d:%02d",
        now.year(), now.month(), now.day(),
        now.hour(), now.minute(),now.second() );
}


/* This is example for SHT3X-DIS Digital Humidity & Temperature Sensors Arduino Library
ClosedCube SHT31-D [Digital I2C] Humidity and Temperature Sensor Breakout
MIT License
*/
// print_sht30_result("Pooling Mode", sht3xd.readTempAndHumidity(SHT3XD_REPEATABILITY_HIGH, SHT3XD_MODE_POLLING, 50));
void get_sht30_data() {
    SHT31D result = sht3xd.readTempAndHumidity(SHT3XD_REPEATABILITY_HIGH, SHT3XD_MODE_POLLING, 50);
    if (result.error == SHT3XD_NO_ERROR) {
        char temp_str[8];
        dtostrf(result.t, 5, 1, temp_str);

        char humd_str[8];
        dtostrf(result.rh, 5, 1, humd_str);
       // sprintf(temp_humd_string, "%fC,%f%", result.t, result,rh);
        sprintf(temp_humd_string, "%sC,%s%%, ", temp_str, humd_str);
    } else {
        sprintf(temp_humd_string, "ERR:%d, ", result.error);
    }
}

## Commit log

2020-05-23 Inital PCB Footprint Placements
    Thank you to everyone in the live stream chat.
    [Bald Sense Wing v1.kicad_pcb, Bald Sense Wing v1.sch]
2020-05-23 Re-arranged PCB
    Moved SD Card slot to other side and put sensors on an edge.
    [Bald Sense Wing v1.kicad_pcb, Bald Sense Wing v1.sch]
2020-05-23 Re-arranged PCB parts to a more logical layout
    Switched to SOT-23 3906 because the SO70 looked too small.
    Switched PDM to a Cui CMM-4737DT-26186.
    Fixed two-pin header footprint (was socket before)
    Changed to 10mm battery holder
    Changed Footprint reference sizes
    [Bald Sense Wing v1.kicad_pcb, Bald Sense Wing v1.sch]
2020-05-24 Minor updates
    [Bald Sense Wing v1-before rough layout.kicad_pcb, Bald Sense Wing v1.sch]
2020-05-28 Finished v1 layout
    Thanks to everyone on the stream!
    [Bald Sense Wing v1.kicad_pcb, Bald Sense Wing v1.sch]
2020-05-30 Fixed courtyards and updated silkscreens
    [Bald Sense Wing v1.kicad_pcb]
2020-06-04 Cleaned up silkscreens and submitted board
    [Bald Sense Wing v1.kicad_pcb]
2022-04-20 moved kicad files to separate directory
    [Bald Sense Wing v1-before rough layout.kicad_pcb, Bald Sense Wing v1.kicad_pcb, Bald Sense Wing v1.sch]
2022-04-20 adding old arduino project
2022-04-21 added light sensor to m0 code.
2022-05-04 kicad 6 update
2024-05-21 ignorning old kicad temp files
2024-05-21 re-organized files and setup for v3
    [Bald Sense Wing v1-before rough layout.kicad_pcb, Bald Sense Wing v1.kicad_pcb, Bald Sense Wing v1.sch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]
2024-06-15 re-worked pinout to match m0 lora feather
    [Bald Sense Wing v3.kicad_pcb, Bald Sense Wing v3.kicad_sch]
2024-06-15 removed LDO and unconnected a few pins to be compatible with feathers3
    [Bald Sense Wing v3.kicad_sch]
2024-06-15 changed R to 0402 and C to 0603
    [Bald Sense Wing v3.kicad_pcb, Bald Sense Wing v3.kicad_sch]
2024-06-20 Cleaned up older custom symbols. Ran track clean-up on PCB.
    [Bald Sense Wing v3.kicad_pcb, Bald Sense Wing v3.kicad_sch]
2024-06-20 updated pin header silk
    [Bald Sense Wing v3.kicad_pcb]
2024-06-24 added load switch and changed power markers
    [Bald Sense Wing v3.kicad_pcb, Bald Sense Wing v3.kicad_sch]
2024-06-24 re-worked pin assignments of custom packages and passed ERC
    [Bald Sense Wing v3.kicad_sch]
2024-06-24 added stemma qt connector
    [Bald Sense Wing v3.kicad_sch]
2024-06-25 14 unrouted
    [Bald Sense Wing v3.kicad_pcb, Bald Sense Wing v3.kicad_sch]
2024-06-25 working on voltage rails
    [Bald Sense Wing v3.kicad_pcb]
2024-06-25 first to 0 unrouted!
    [Bald Sense Wing v3.kicad_pcb]
2024-06-25 Cleaned up power rails. Prepping for Macrofab DRC
    [Bald Sense Wing v3.kicad_pcb]
2024-06-25 updated custom footprints with (local) 3d models. ready for fab.
    [Bald Sense Wing v3.kicad_pcb]
2024-06-25 updated pns
    [Bald Sense Wing v3.kicad_sch]
2024-06-26 Edge Cut issue with mismatched widths
    [Bald Sense Wing v3.kicad_pcb]
2024-06-26 cleaned up schematic
    [Bald Sense Wing v3.kicad_sch]
2024-06-26 design review changes incorporated
    [Bald Sense Wing v3.kicad_pcb]
2024-06-26 rev3 v2 fab submit
    [Bald Sense Wing v3-B_Cu.gbr, Bald Sense Wing v3-B_Mask.gbr, Bald Sense Wing v3-B_Paste.gbr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]
2024-07-20 tried adding PDM but not supported on esp32 :(
2024-07-20 battery and usb voltage measurements
2024-07-29 STEP export for enclosure
    [Bald Sense Wing v3.step]
2024-11-30 stls for enclosure
    [Baseplate.3mf, Baseplate.stl, Cover.3mf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]
2024-12-08 added i2c not connected handling
2024-12-08 cutout for USB (won't be sealed but will be protected)
    [Cover with USB Cutout.3mf, Cover with USB Cutout.stl]
2024-12-08 adds build number, fixes #9
    [code.py]
